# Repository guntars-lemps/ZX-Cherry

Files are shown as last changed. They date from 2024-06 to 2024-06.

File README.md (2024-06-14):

The ZX Cherry is a keyboard replacement for the ZX Spectrum plus membrane keyboard based on Cherry MX switches. The keyboard keeps the original look of the ZX Spectrum plus which has a much better and more durable keyboard. For extended keys, the BU4066 (or compatible) switches and other elements are used. I suggest to use brown cherry switches, they are noiseless and have tactile feedback.

To use ZX Cherry keyboard together with the original zx spectrum board, the ribbon cable connectors should be replaced with wired connectors, and additionally two power wires must be routed together with the KB0..KB4 wires to JP1 connector

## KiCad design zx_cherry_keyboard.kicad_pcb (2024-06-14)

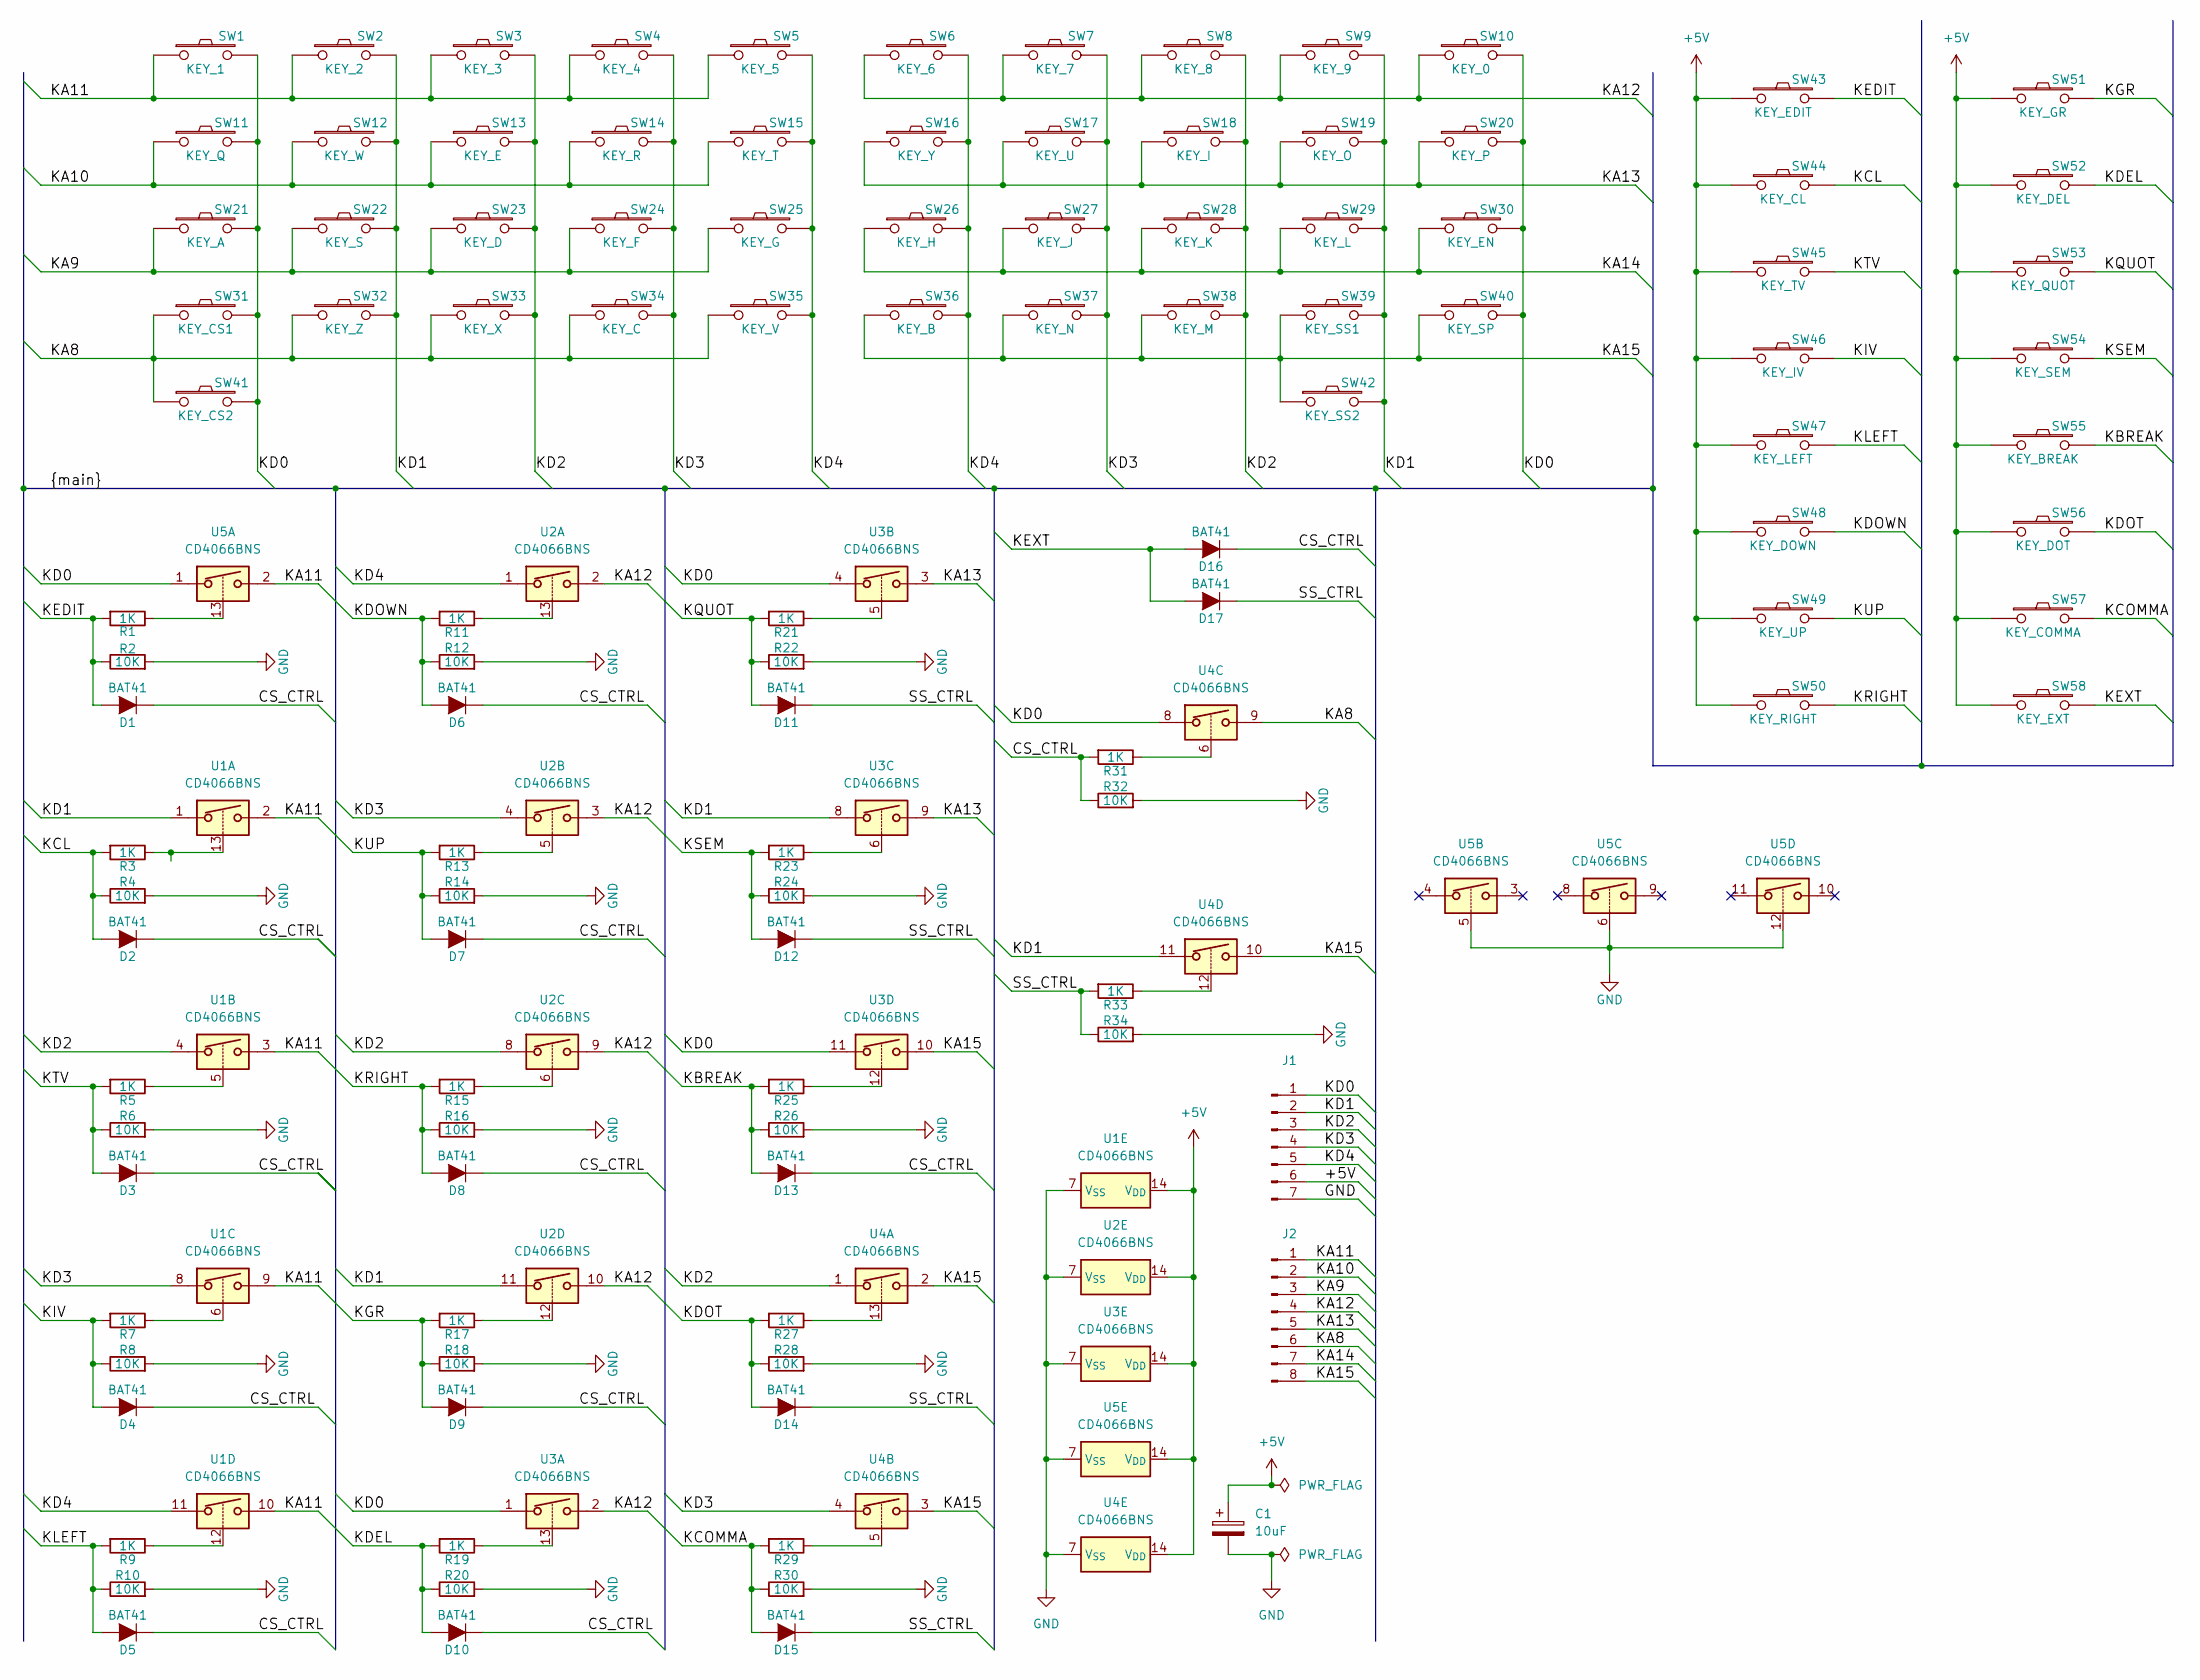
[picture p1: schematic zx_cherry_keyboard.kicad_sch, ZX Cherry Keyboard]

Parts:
C1: 10uF; CP_EIA-7343-43_Kemet-X_Pad2.25x2.55mm_HandSolder
D1, D2, D3, D4, D5, D6, D7, D8, D9, D10, D11, D12, D13, D14, D15, D16, D17: BAT41; D_DO-35_SOD27_P12.70mm_Horizontal
J1: Conn_01x07_Pin; PinHeader_1x07_P2.54mm_Horizontal
J2: Conn_01x08_Pin; PinHeader_1x08_P2.54mm_Horizontal
R1, R3, R5, R7, R9, R11, R13, R15, R17, R19, R21, R23, R25, R27, R29, R31, R33: 1K; R_0805_2012Metric_Pad1.20x1.40mm_HandSolder
R2, R4, R6, R8, R10, R12, R14, R16, R18, R20, R22, R24, R26, R28, R30, R32, R34: 10K; R_0805_2012Metric_Pad1.20x1.40mm_HandSolder
SW1: KEY_1; SW_Cherry_MX_1.00u_Plate
SW2: KEY_2; SW_Cherry_MX_1.00u_Plate
SW3: KEY_3; SW_Cherry_MX_1.00u_Plate
SW4: KEY_4; SW_Cherry_MX_1.00u_Plate
SW5: KEY_5; SW_Cherry_MX_1.00u_Plate
SW6: KEY_6; SW_Cherry_MX_1.00u_Plate
SW7: KEY_7; SW_Cherry_MX_1.00u_Plate
SW8: KEY_8; SW_Cherry_MX_1.00u_Plate
SW9: KEY_9; SW_Cherry_MX_1.00u_Plate
SW10: KEY_0; SW_Cherry_MX_1.00u_Plate
SW11: KEY_Q; SW_Cherry_MX_1.00u_Plate
SW12: KEY_W; SW_Cherry_MX_1.00u_Plate
SW13: KEY_E; SW_Cherry_MX_1.00u_Plate
SW14: KEY_R; SW_Cherry_MX_1.00u_Plate
SW15: KEY_T; SW_Cherry_MX_1.00u_Plate
SW16: KEY_Y; SW_Cherry_MX_1.00u_Plate
SW17: KEY_U; SW_Cherry_MX_1.00u_Plate
SW18: KEY_I; SW_Cherry_MX_1.00u_Plate
SW19: KEY_O; SW_Cherry_MX_1.00u_Plate
SW20: KEY_P; SW_Cherry_MX_1.00u_Plate
SW21: KEY_A; SW_Cherry_MX_1.00u_Plate
SW22: KEY_S; SW_Cherry_MX_1.00u_Plate
SW23: KEY_D; SW_Cherry_MX_1.00u_Plate
SW24: KEY_F; SW_Cherry_MX_1.00u_Plate
SW25: KEY_G; SW_Cherry_MX_1.00u_Plate
SW26: KEY_H; SW_Cherry_MX_1.00u_Plate
SW27: KEY_J; SW_Cherry_MX_1.00u_Plate
SW28: KEY_K; SW_Cherry_MX_1.00u_Plate
SW29: KEY_L; SW_Cherry_MX_1.00u_Plate
SW30: KEY_EN; SW_Cherry_MX_1.00u_Plate
SW31: KEY_CS1; SW_Cherry_MX_1.00u_Plate
SW32: KEY_Z; SW_Cherry_MX_1.00u_Plate
SW33: KEY_X; SW_Cherry_MX_1.00u_Plate
SW34: KEY_C; SW_Cherry_MX_1.00u_Plate
SW35: KEY_V; SW_Cherry_MX_1.00u_Plate
SW36: KEY_B; SW_Cherry_MX_1.00u_Plate
SW37: KEY_N; SW_Cherry_MX_1.00u_Plate
SW38: KEY_M; SW_Cherry_MX_1.00u_Plate
SW39: KEY_SS1; SW_Cherry_MX_1.00u_Plate
SW40: KEY_SP; SW_Cherry_MX_1.00u_Plate
SW41: KEY_CS2; SW_Cherry_MX_1.00u_Plate
SW42: KEY_SS2; SW_Cherry_MX_1.00u_Plate
SW43: KEY_EDIT; SW_Cherry_MX_1.00u_Plate
SW44: KEY_CL; SW_Cherry_MX_1.00u_Plate
SW45: KEY_TV; SW_Cherry_MX_1.00u_Plate
SW46: KEY_IV; SW_Cherry_MX_1.00u_Plate
SW47: KEY_LEFT; SW_Cherry_MX_1.00u_Plate
SW48: KEY_DOWN; SW_Cherry_MX_1.00u_Plate
SW49: KEY_UP; SW_Cherry_MX_1.00u_Plate
SW50: KEY_RIGHT; SW_Cherry_MX_1.00u_Plate
SW51: KEY_GR; SW_Cherry_MX_1.00u_Plate
SW52: KEY_DEL; SW_Cherry_MX_1.00u_Plate
SW53: KEY_QUOT; SW_Cherry_MX_1.00u_Plate
SW54: KEY_SEM; SW_Cherry_MX_1.00u_Plate
SW55: KEY_BREAK; SW_Cherry_MX_1.00u_Plate
SW56: KEY_DOT; SW_Cherry_MX_1.00u_Plate
SW57: KEY_COMMA; SW_Cherry_MX_1.00u_Plate
SW58: KEY_EXT; SW_Cherry_MX_1.00u_Plate
U1, U2, U3, U4, U5: CD4066BNS; SO-14_5.3x10.2mm_P1.27mm

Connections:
+5V: C1.1, J1.6, SW43.1, SW44.1, SW45.1, SW46.1, SW47.1, SW48.1, SW49.1, SW50.1, SW51.1, SW52.1, SW53.1, SW54.1, SW55.1, SW56.1, SW57.1, SW58.1, U1.14 (V_{DD}), U2.14 (V_{DD}), U3.14 (V_{DD}), U4.14 (V_{DD}), U5.14 (V_{DD})
/CS_CTRL: D1.1 (K), D2.1 (K), D3.1 (K), D4.1 (K), D5.1 (K), D6.1 (K), D7.1 (K), D8.1 (K), D9.1 (K), D10.1 (K), D13.1 (K), D16.1 (K), R31.2, R32.1
/KA8: J2.6, SW31.1, SW32.1, SW33.1, SW34.1, SW35.1, SW41.1, U4.9
/KA9: J2.3, SW21.1, SW22.1, SW23.1, SW24.1, SW25.1
/KA10: J2.2, SW11.1, SW12.1, SW13.1, SW14.1, SW15.1
/KA11: J2.1, SW1.1, SW2.1, SW3.1, SW4.1, SW5.1, U1.2, U1.3, U1.9, U1.10, U5.2
/KA12: J2.4, SW6.1, SW7.1, SW8.1, SW9.1, SW10.1, U2.2, U2.3, U2.9, U2.10, U3.2
/KA13: J2.5, SW16.1, SW17.1, SW18.1, SW19.1, SW20.1, U3.3, U3.9
/KA14: J2.7, SW26.1, SW27.1, SW28.1, SW29.1, SW30.1
/KA15: J2.8, SW36.1, SW37.1, SW38.1, SW39.1, SW40.1, SW42.1, U3.10, U4.2, U4.3, U4.10
/KBREAK: D13.2 (A), R25.2, R26.1, SW55.2
/KCL: D2.2 (A), R3.2, R4.1, SW44.2
/KCOMMA: D15.2 (A), R29.2, R30.1, SW57.2
/KD0: J1.1, SW1.2, SW10.2, SW11.2, SW20.2, SW21.2, SW30.2, SW31.2, SW40.2, SW41.2, U3.1, U3.4, U3.11, U4.8, U5.1
/KD1: J1.2, SW2.2, SW9.2, SW12.2, SW19.2, SW22.2, SW29.2, SW32.2, SW39.2, SW42.2, U1.1, U2.11, U3.8, U4.11
/KD2: J1.3, SW3.2, SW8.2, SW13.2, SW18.2, SW23.2, SW28.2, SW33.2, SW38.2, U1.4, U2.8, U4.1
/KD3: J1.4, SW4.2, SW7.2, SW14.2, SW17.2, SW24.2, SW27.2, SW34.2, SW37.2, U1.8, U2.4, U4.4
/KD4: J1.5, SW5.2, SW6.2, SW15.2, SW16.2, SW25.2, SW26.2, SW35.2, SW36.2, U1.11, U2.1
/KDEL: D10.2 (A), R19.2, R20.1, SW52.2
/KDOT: D14.2 (A), R27.2, R28.1, SW56.2
/KDOWN: D6.2 (A), R11.2, R12.1, SW48.2
/KEDIT: D1.2 (A), R1.2, R2.1, SW43.2
/KEXT: D16.2 (A), D17.2 (A), SW58.2
/KGR: D9.2 (A), R17.2, R18.1, SW51.2
/KIV: D4.2 (A), R7.2, R8.1, SW46.2
/KLEFT: D5.2 (A), R9.2, R10.1, SW47.2
/KQUOT: D11.2 (A), R21.2, R22.1, SW53.2
/KRIGHT: D8.2 (A), R15.2, R16.1, SW50.2
/KSEM: D12.2 (A), R23.2, R24.1, SW54.2
/KTV: D3.2 (A), R5.2, R6.1, SW45.2
/KUP: D7.2 (A), R13.2, R14.1, SW49.2
/SS_CTRL: D11.1 (K), D12.1 (K), D14.1 (K), D15.1 (K), D17.1 (K), R33.2, R34.1
GND: C1.2, J1.7, R2.2, R4.2, R6.2, R8.2, R10.2, R12.2, R14.2, R16.2, R18.2, R20.2, R22.2, R24.2, R26.2, R28.2, R30.2, R32.2, R34.2, U1.7 (V_{SS}), U2.7 (V_{SS}), U3.7 (V_{SS}), U4.7 (V_{SS}), U5.5, U5.6, U5.7 (V_{SS}), U5.12
unnamed: R1.1, U5.13
unnamed: R3.1, U1.13
unnamed: R5.1, U1.5
unnamed: R7.1, U1.6
unnamed: R9.1, U1.12
unnamed: R11.1, U2.13
unnamed: R13.1, U2.5
unnamed: R15.1, U2.6
unnamed: R17.1, U2.12
unnamed: R19.1, U3.13
unnamed: R21.1, U3.5
unnamed: R23.1, U3.6
unnamed: R25.1, U3.12
unnamed: R27.1, U4.13
unnamed: R29.1, U4.5
unnamed: R31.1, U4.6
unnamed: R33.1, U4.12

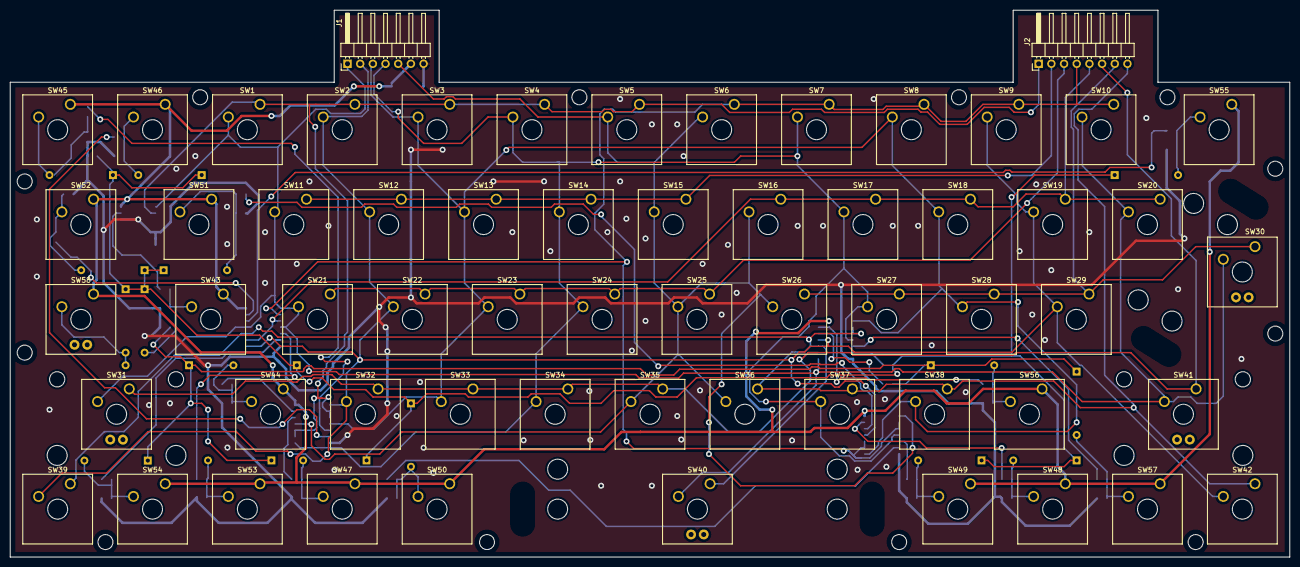
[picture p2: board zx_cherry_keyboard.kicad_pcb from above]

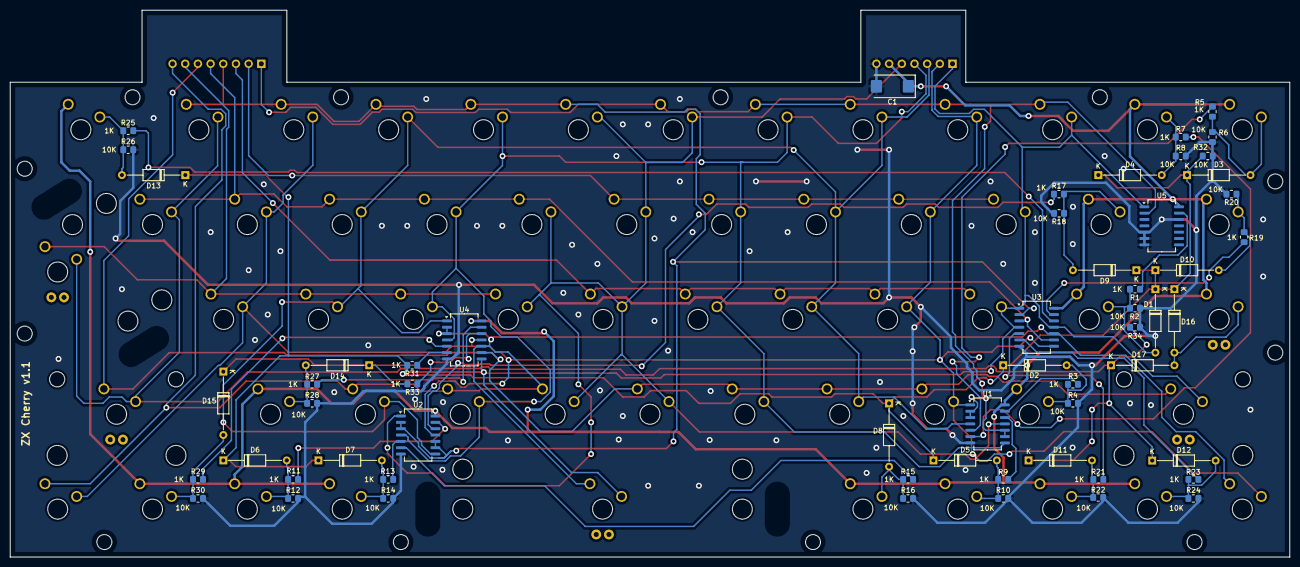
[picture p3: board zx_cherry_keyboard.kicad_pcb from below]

Board: 2 copper layers, 256.3 x 109.5 mm, 117 parts (57 on the bottom side), 50 nets.

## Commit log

2018-05-30 mainboard schematics & pcb
    [zx_mainboard.kicad_pcb, zx_mainboard.sch]
2018-05-31 mainboard pcb
    [zx_mainboard.kicad_pcb]
2018-06-13 keyboard pcb
    [zx_keyboard.kicad_pcb]
2018-07-28 TV<->IV fix
    [zx_keyboard.kicad_pcb]
2024-06-14 rev1.1 release
    [zx_cherry_keyboard.kicad_pcb, zx_cherry_keyboard.kicad_sch, zx_keyboard.kicad_pcb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]
